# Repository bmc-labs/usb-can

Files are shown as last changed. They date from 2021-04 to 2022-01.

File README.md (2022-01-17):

# `usb-can`, a simple and cost effective CAN link

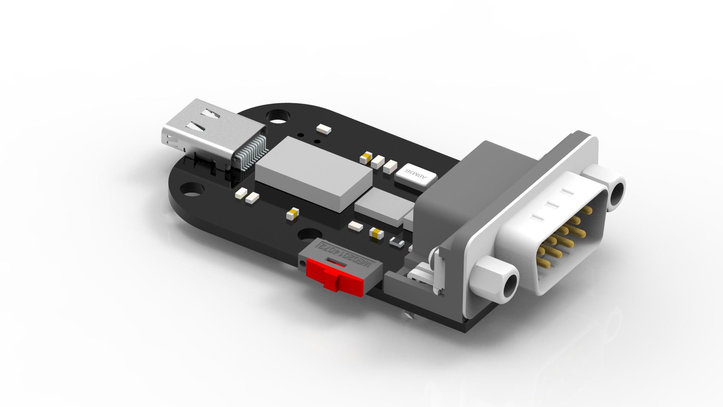
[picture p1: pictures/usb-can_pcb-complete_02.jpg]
bmc::labs

_Rendering of `usb-can`, our version of the USBtin by Thomas Fischl_

Be it for automation, development or debugging, one often needs a way to
inspect a CAN bus. This device allows to connect to a CAN bus via a standard
USB type C cable. It is based on the [USBtin by Thomas
Fischl](https://www.fischl.de/usbtin/) - there are many great resources behind
this link, and we encourage you to buy Thomas' version from him!

All examplatory output comes from a 2013 MacBook Pro running Debian.

## Use with Linux
Start by adding yourself to the `dialout` group if you aren't already in it:

```bash
» sudo usermod -aG dialout $USER
```

You'll need [`can-utils` for Linux](https://github.com/linux-can/can-utils).
If you're on something Debian-based, you're best off installing them like so:

```bash
» sudo apt install can-utils
```

If you're on a different distro, you may find the `can-utils` in your
respective package management; if not go get them [from
GitHub](https://github.com/linux-can/can-utils). Good, now you're all set.

#### Loading kernel modules
CAN support via `socketcan` is upstream in Linux, but it is not necessarily
loaded by default. Execute load like so:

```bash
» sudo modprobe can
» sudo modprobe can-raw
» sudo modprobe slcan
```

You can use the `lsmod` utility to verify everything has worked:

```bash
» lsmod | grep can
slcan                  16384  0
can_raw                20480  0
can                    24576  1 can_raw
```

You output may look slightly different, but you should see the modules loaded.

#### Check which serial device is the CAN device
There are a number of ways to do this. First off, you may want to check that
the `usb-can` is actually recognized via `lsusb` (which you may have to
install):

```bash
» lsusb
...
Bus 002 Device 015: ID 04d8:000a Microchip Technology, Inc. CDC RS-232 Emulation Demo
...
```

If the device shows up here, you can look which serial port it is bound to:

```bash
» sudo tail /var/log/kern.log
Apr 18 14:53:17 rzrgrl kernel: [64635.125815] usb 2-2: new full-speed USB device number 15 using xhci_hcd
Apr 18 14:53:17 rzrgrl kernel: [64635.276572] usb 2-2: New USB device found, idVendor=04d8, idProduct=000a, bcdDevice= 1.00
Apr 18 14:53:17 rzrgrl kernel: [64635.276580] usb 2-2: New USB device strings: Mfr=1, Product=2, SerialNumber=0
Apr 18 14:53:17 rzrgrl kernel: [64635.276583] usb 2-2: Product: USBtin
Apr 18 14:53:17 rzrgrl kernel: [64635.276585] usb 2-2: Manufacturer: Microchip Technology, Inc.
Apr 18 14:53:17 rzrgrl kernel: [64635.277670] cdc_acm 2-2:1.0: ttyACM0: USB ACM device
```

In this case, it is `ttyACM0`, which should be similar for you.

#### Attach the device to a socket-capable interface
The following commands come from `can-utils`, so if you haven't installed those
so far, do that now.

Next, you should select the bus speed of the CAN you're trying to connect to.
The available speeds are:

| Baudrate (kBaud) | Number encoding | Command paramete |
| :---: | :---: | :---: |
| 1.000 | 8 | `-s8` |
| 800 | 7 | `-s7` |
| 500 | 6 | `-s6` |
| 250 | 5 | `-s5` |
| 125 | 4 | `-s4` |
| 100 | 3 | `-s3` |
| 50 | 2 | `-s2` |
| 20 | 1 | `-s1` |
| 10 | 0 | `-s0` |

Setting up a 500 kBaud CAN interface at serial port `ttyACM0` is done like so:

```bash
» sudo slcan_attach -f -s6 -o /dev/ttyACM0
attached tty /dev/ttyACM0 to netdevice slcan0
» sudo slcand ttyACM0 slcan0
» sudo ip link set slcan0 up
```

**Congratulations, you've done it!**

Now you can send and receive CAN messages on the socket interface `slcan0`. For
example, to dump all incoming messages to the terminal:

```bash
» candump slcan0
```

The `candump` utility also allows you to filter for CAN IDs, set up the byte
order, and a number of other useful things it will tell you about if you as it
nicely (`candump -h`).

Sending a frame to CAN is similarly easy:

```bash
» cansend slcan0 7ff#deadbeef
```

The `cansend` utility is also very vocal about its capabilities if asked.

Further useful components of `can-utils`:

1. the `canplayer` utility, which lets you play CAN messages from a log file
    that looks like this:

    ```
    (0.100) slcan0 5D1#0000
    (0.200) slcan0 271#0100
    (0.300) slcan0 289#72027000
    (0.400) slcan0 401#081100000000
    ```

    The first column is a timestamp allowing for time controlled dumping of the
    frames, the second and third are (hopefully) self-explanatory by now.
2. the `canbusload` utility for analyzing the load on the bus.

Both utilities will also happily tell you about themselves with `-h`.

#### Usage example
Last but not least, here is a snippet for sending the current time in the
format `{hour}{minute}` to the CAN on ID `0x7ff`, i.e. the last and therefore
least priority ID, every 5 seconds:

```bash
while true
do
  cansend slcan0 7ff#$(printf '%02x%02x' $(date +"%I") $(date +"%M"))
  sleep 5
done
```

## Use with Windows, macOS

Please find hints for Windows on [Thomas Fischl's
website](https://www.fischl.de/usbtin/).

For macOS, there is code floating around the web for
[`socketcan`](https://github.com/duraki/socketcanx/) and for
[`can-utils`](https://github.com/carloop/can-utils-osx), and once you have
those working the above guide for Linux should mostly apply. No idea if it
works, though - we don't do macOS right now.

---
_The contents of this repository which are our original work are released into
the public domain unter The Unlicense (see [LICENSE](./LICENSE)). We build
heavily on the work of others here and recommend you pay them tribute first if
you like the material you've found here._

## Create your own

### Bill of Materials
- 1x [usb-can_housing-lower](https://gitlab.bmc-labs.com/bmc-board/usb-can/-/blob/trunk/design-files/usb-can_housing-lower.step) (3d print)
- 1x [usb-can_housing-lower-clean](https://gitlab.bmc-labs.com/bmc-board/usb-can/-/blob/trunk/design-files/usb-can_housing-upper-clean.step) or [-icon](https://gitlab.bmc-labs.com/bmc-board/usb-can/-/blob/trunk/design-files/usb-can_housing-upper-icon.step) version (3d print)
- 4x [Socket screw M3x8mm](https://uk.rs-online.com/web/p/socket-screws/1871213)
- 4x [Thread insert M3x4.78mm](https://uk.rs-online.com/web/p/threaded-inserts/0278534/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)
- 1x usb-can PCB board

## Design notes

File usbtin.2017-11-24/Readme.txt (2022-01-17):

USBtin - Simple USB to CAN interface
------------------------------------

This archive contains firmware, drivers and bootloader for the USBtin project.
USBtin is a simple USB to CAN interface. You find further information about
USBtin on the project homepage: http://www.fischl.de/usbtin

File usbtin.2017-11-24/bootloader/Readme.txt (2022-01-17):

Bootloader for USBtin
---------------------

The bootloader for USBtin is adapted from Microchips USB HID Bootloader for
PIC18 Non-J Families (/microchip/mla/v2015_08_10/apps/usb/device/bootloaders/
firmware/pic18_non_j).

Device:
USBtin with PIC18F14K50

Changes:
- Use Jumper to enter bootloader
- Set up clock from MCP2515
- Disabled EEPROM functions to reduce code size
- Added USB serialnumber string

Licence:
The bootloader is closed source. The binary (hex) file is provided free for
personal use. For closed or commercial projects you have to contact the author
to get the permission for using this source code.

Usage:
Program the bootloader into the device/USBtin with a programmer which
supports PIC18 controllers (e.g. PicKit 3).
To enter the bootloader, set the bootloader jumper (JP1) on USBtin before
connecting it to the USB. Then you can use a loader application to update the
firmware. "mphidflash" is such an application. Example:
mphidflash -write USBtin_firmware_v1.x.hex
After flashing a new fimware, disconnect the USBtin from the USB and open the
jumper before reconnecting the device to the host pc.

History:
- 2012-02-09   v1.0    Initial version (based on MLA v2011-10-18-beta)
- 2016-04-13   v1.1    Added USB serialnumber string (based on MLA v2015_08_10)

2016-04-13 Thomas Fischl <tfischl@gmx.de>
http://www.fischl.de/usbtin/

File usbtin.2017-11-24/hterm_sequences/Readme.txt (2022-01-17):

This folder contains HTerm sequence files for the USBtin. HTerm is a terminal program available
for Windows and Linux:
http://www.der-hammer.info/terminal/

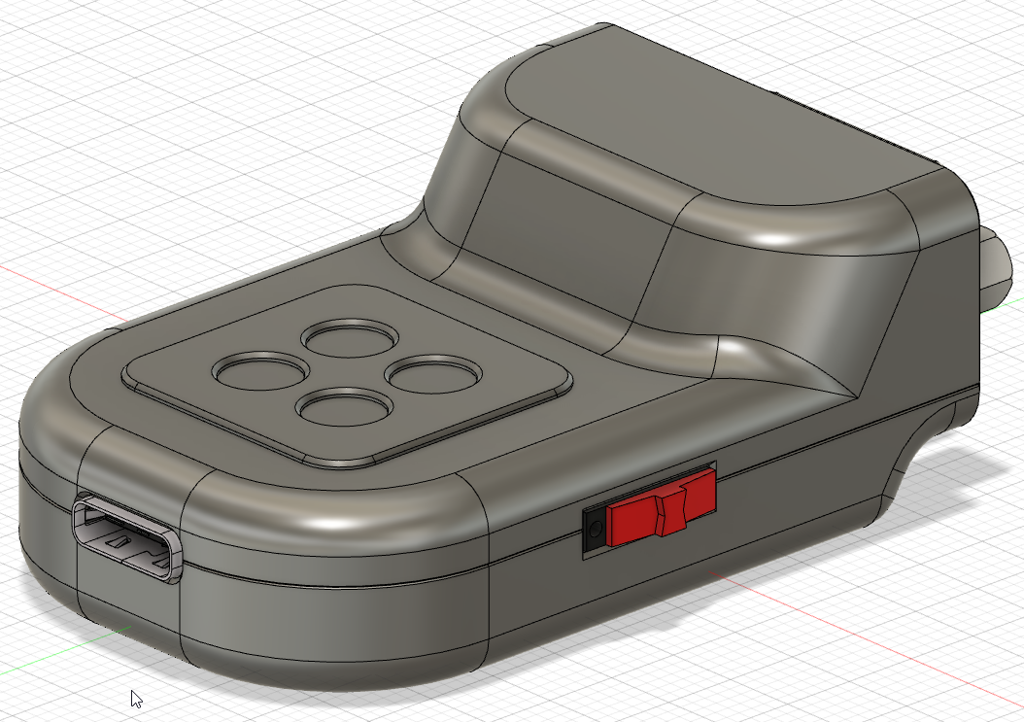
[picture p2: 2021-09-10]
pictures/usb-can_01.png

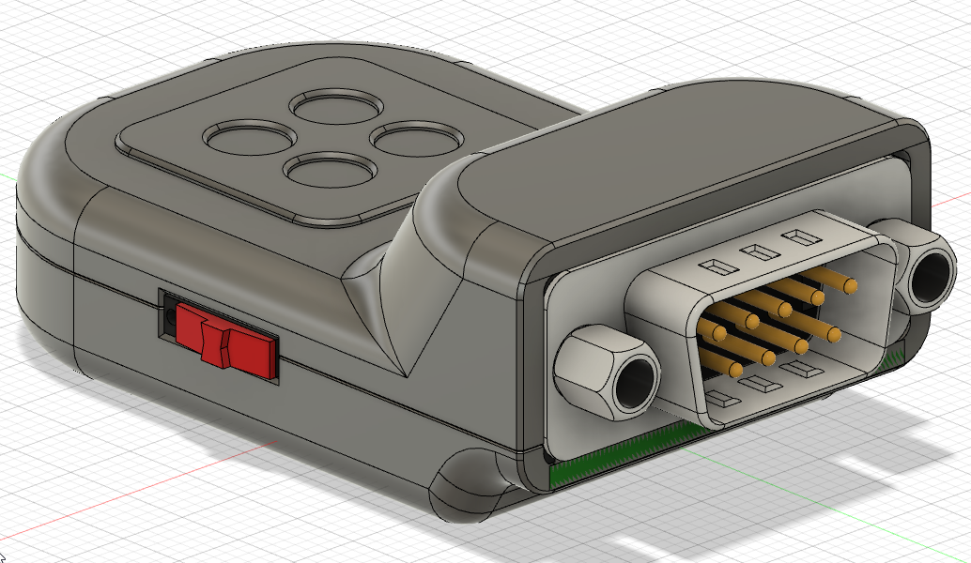
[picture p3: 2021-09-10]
pictures/usb-can_06.png

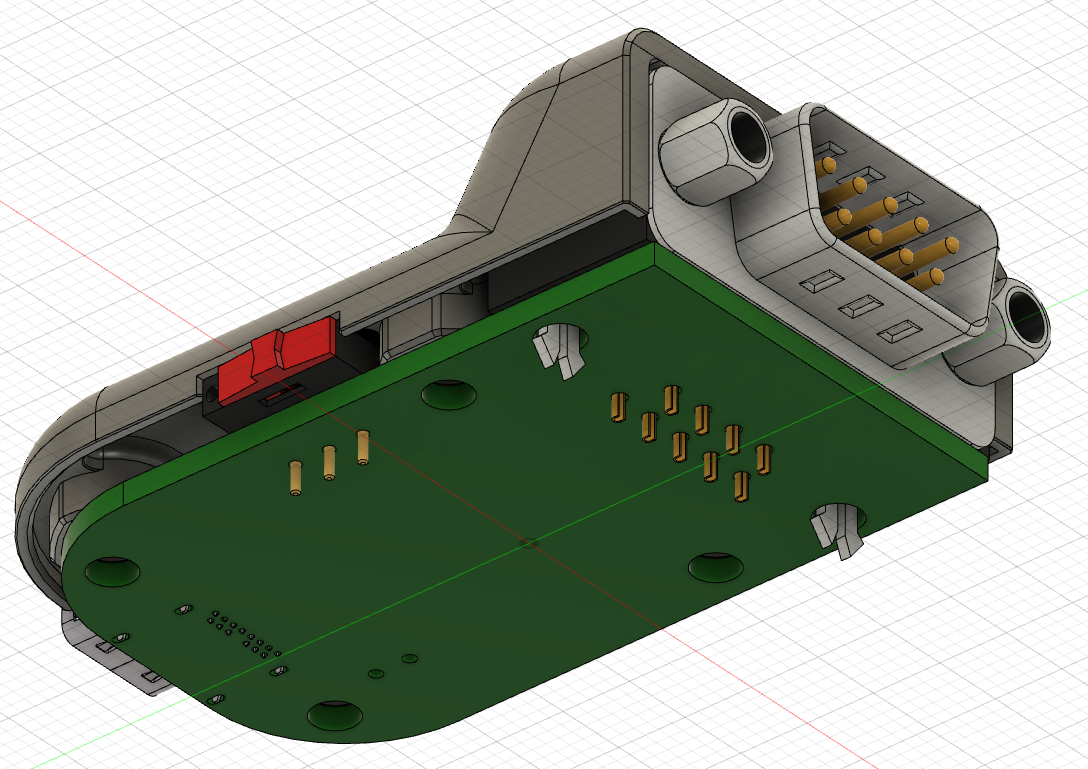
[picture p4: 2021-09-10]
pictures/usb-can_03.png

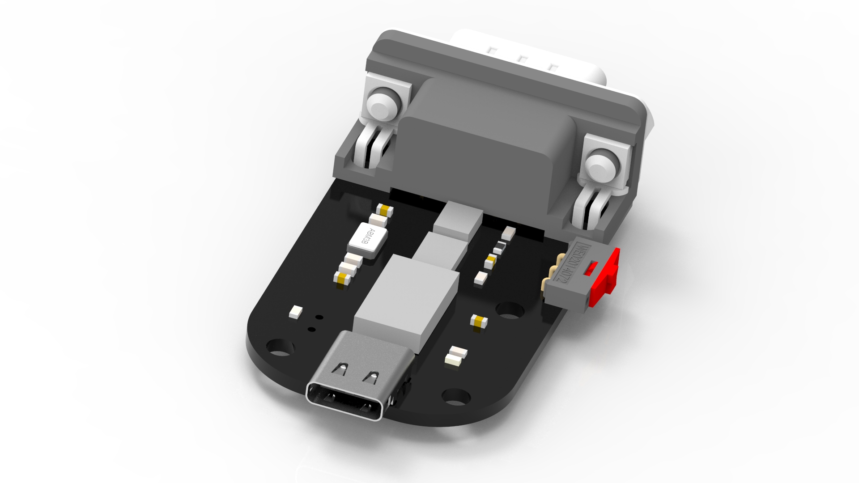
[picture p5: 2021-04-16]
pictures/usb-can_pcb-complete_01.jpg

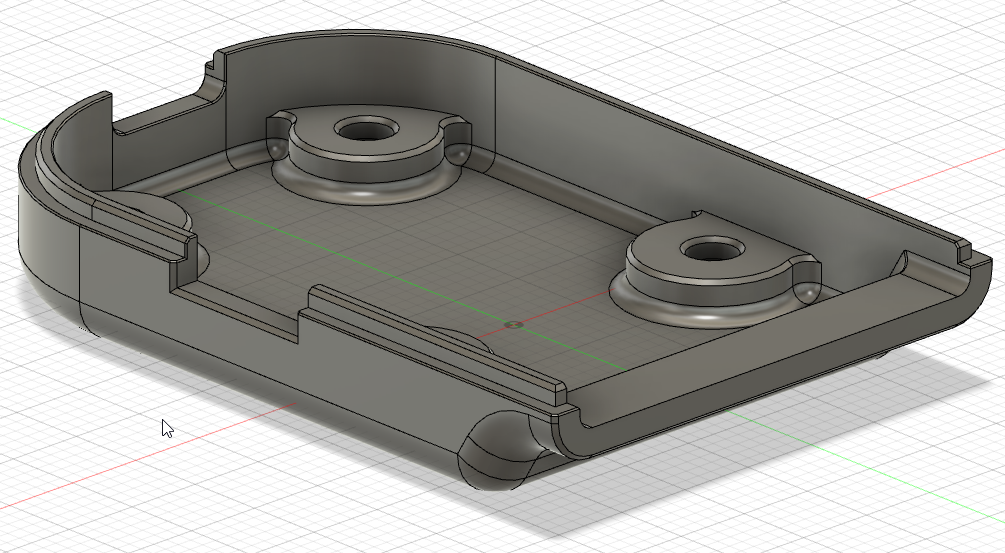
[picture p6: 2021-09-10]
pictures/usb-can_05.png

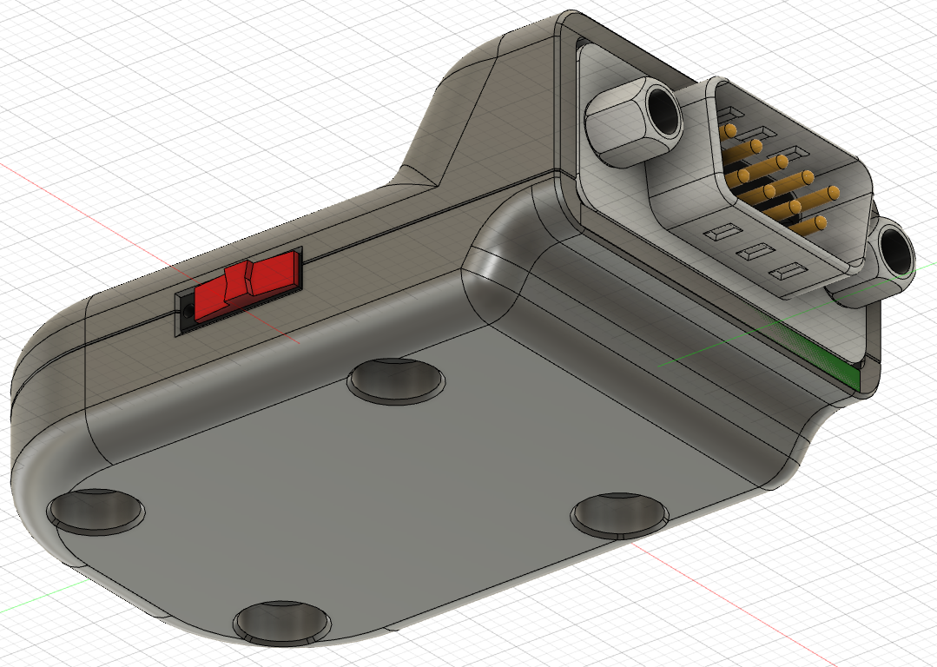
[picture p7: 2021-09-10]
pictures/usb-can_02.png

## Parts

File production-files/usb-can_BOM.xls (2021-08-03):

 |  | Component list |  | usb-can
 |  | Source Data From: |  | USBtin EB.PrjPcb
 |  | Project: |  | USBtin EB.PrjPcb
 |  | Variant: |  | None
 |  | Report Date: | 20.04.2021 | 11:06:44
Description | Manufacturer Part Number | Designator | Quantity | Description | Comment
CAP, 4.7UF, 16V, MLCC, 0603; SVHC: No SVHC (15-Jan-2019) RoHS Compliant: Yes |  | C1 | 1 | CAP, 4.7UF, 16V, MLCC, 0603; SVHC: No SVHC (15-Jan-2019) RoHS Compliant: Yes | 4.7uF
CAP CER 0.1UF 16V 10% X7R 0603 |  | C2, C3, C4, C5 | 4 | CAP CER 0.1UF 16V 10% X7R 0603 | 100nF
CAP CER 22PF 50V 2% NP0 0603 | 06035U220GAT2A | C6, C7 | 2 | CAP CER 22PF 50V 2% NP0 0603 | 22pF
Board-To-Board Connector, Right Angle, WR-PHD Series, Through Hole, Header, 2, 2.54 mm | 61300211021 | J1 | 1 | Board-To-Board Connector, Right Angle, WR-PHD Series, Through Hole, Header, 2, 2.54 mm | Würth Elektronik 61300211021
D Sub Connector, Right Angle, R/a Pcb Mount D Sub, De, Plug, 9, Solder Rohs Compliant: Yes |  | J2 | 1 | D Sub Connector, Right Angle, R/a Pcb Mount D Sub, De, Plug, 9, Solder Rohs Compliant: Yes | Value
Soft Orange 0603 160º 15 mA 1.8 V 7.5 mcd Surface Mount LED | TLMO1000-GS08 | LED1 | 1 | Soft Orange 0603 160º 15 mA 1.8 V 7.5 mcd Surface Mount LED | Vishay TLMO1000-GS08
Res Thin Film 0603 1K Ohm 1% 1/10W ±50ppm/°C Molded SMD SMD Paper T/R | MCT06030C1001FP500 | R1, R3 | 2 | Res Thin Film 0603 1K Ohm 1% 1/10W ±50ppm/°C Molded SMD SMD Paper T/R | 1k
Thick Film Resistors 0603 200ohms 5% Tol | ERJ-3GEYJ201V | R2 | 1 | Thick Film Resistors 0603 200ohms 5% Tol | 200R
Precision resistor, SMD [Panasonic Automotive & Industrial Systems] ERJ3EKF1200V Precision resistor, SMD |  | R4 | 1 | Precision resistor, SMD [Panasonic Automotive & Industrial Systems] ERJ3EKF1200V Precision resistor, SMD | 120R
Metal Film Resistors 10K OHM .1% 25PPM | ERA-3YEB103V | R17 | 1 | Metal Film Resistors 10K OHM .1% 25PPM | 10k
WS-SLTU 10mm*2.5mm, SPDT, ON-ON, 2.54mm, right angle type, THT, Mini Slide Switch, 3 pins | 450302014072 | SW1 | 1 | WS-SLTU 10mm*2.5mm, SPDT, ON-ON, 2.54mm, right angle type, THT, Mini Slide Switch, 3 pins | 450302014072
USB Flash Microcontroller with nanoWatt XLP Technology, 20-pin SOIC, Industrial Temperature, Tape and Reel | PIC18F14K50T-I/SO | U1 | 1 | USB Flash Microcontroller with nanoWatt XLP Technology, 20-pin SOIC, Industrial Temperature, Tape and Reel | PIC18F14K50T-I/SO
Automotive Catalog EMC Optimized CAN Transceiver, 70 mA, 5 V, -40 to 125 degC, 8-pin SOIC (D), Green (RoHS & no Sb/Br) | SN65HVD1050QDRQ1 | U2 | 1 | Automotive Catalog EMC Optimized CAN Transceiver, 70 mA, 5 V, -40 to 125 degC, 8-pin SOIC (D), Green (RoHS & no Sb/Br) | SN65HVD1050QDRQ1
MCP2515 Series 5.5 V 1 Mb/s Stand Alone SPI Interface CAN Controller- TSSOP-20 | MCP2515T-I/ST | U3 | 1 | MCP2515 Series 5.5 V 1 Mb/s Stand Alone SPI Interface CAN Controller- TSSOP-20 | COM-CAN-MCP2515-20
USB 3.1 Type C Receptacle WR-COM, Horizontal, SMT / THT | 632723100011 | USB | 1 | USB 3.1 Type C Receptacle WR-COM, Horizontal, SMT / THT | Würth Elektronik 632723100011
Ceramic SMD Crystal, 24 MHz, +/- 20 ppm, 50 Ohm, -20 to 70 degC, 4-Pin SMD, RoHS, Tape and Reel | ABM3B-24.000MHZ-B2-T | X1 | 1 | Ceramic SMD Crystal, 24 MHz, +/- 20 ppm, 50 Ohm, -20 to 70 degC, 4-Pin SMD, RoHS, Tape and Reel | Abracon ABM3B-24.000MHZ-B2-T

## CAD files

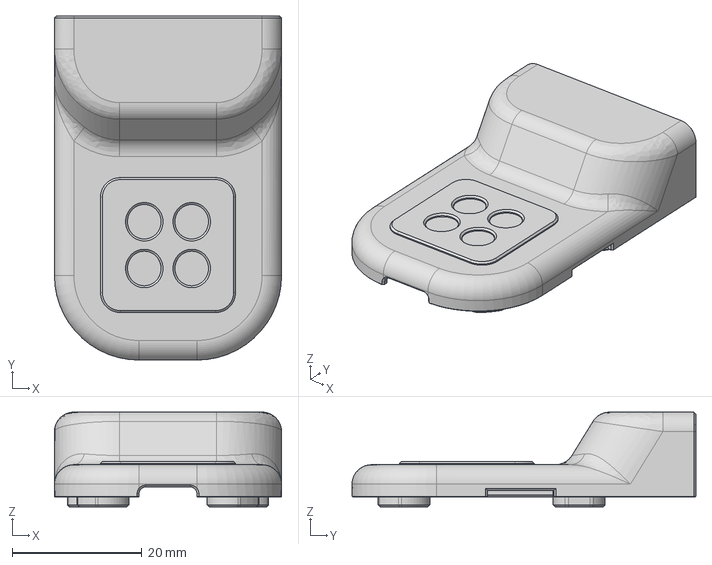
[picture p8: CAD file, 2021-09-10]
design-files/usb-can_housing-upper-icon.step
35.0 x 53.0 x 14.6 mm

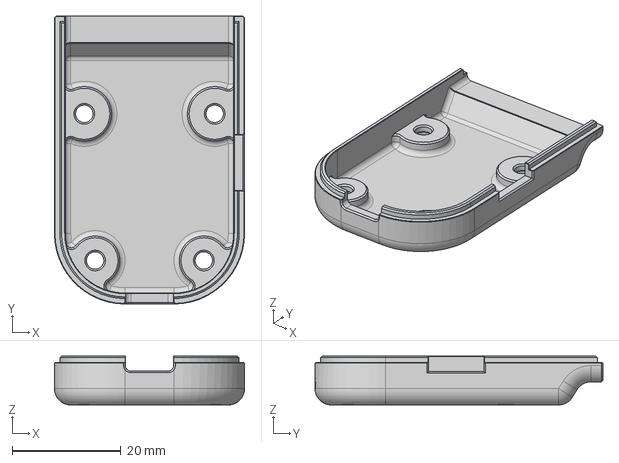
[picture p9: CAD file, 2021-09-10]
design-files/usb-can_housing-lower.step
35.0 x 53.0 x 9.00 mm

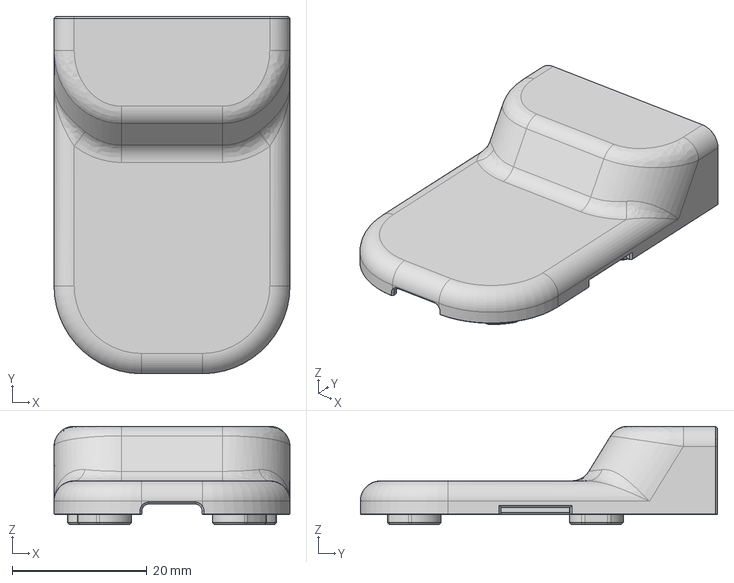
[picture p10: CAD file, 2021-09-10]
design-files/usb-can_housing-upper-clean.step
35.0 x 53.0 x 14.6 mm

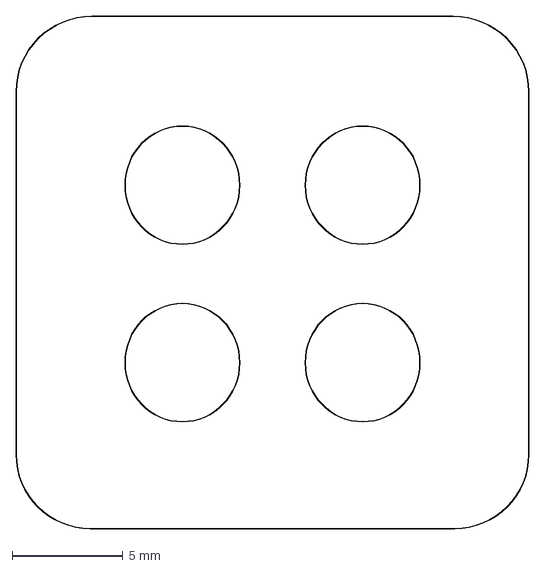
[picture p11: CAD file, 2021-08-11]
design-files/usb-can_sketch-bmc-icon_1.0.0.dxf
23.1 x 23.1 mm

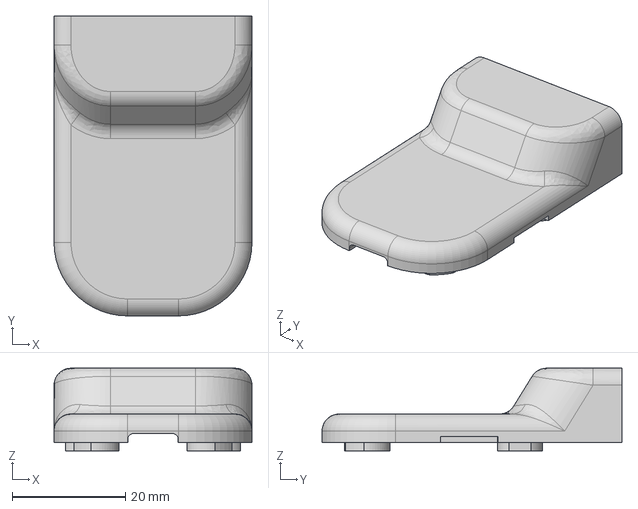
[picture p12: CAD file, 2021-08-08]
design-files/usb-can_v12_housing-upper.step
35.0 x 53.0 x 14.6 mm

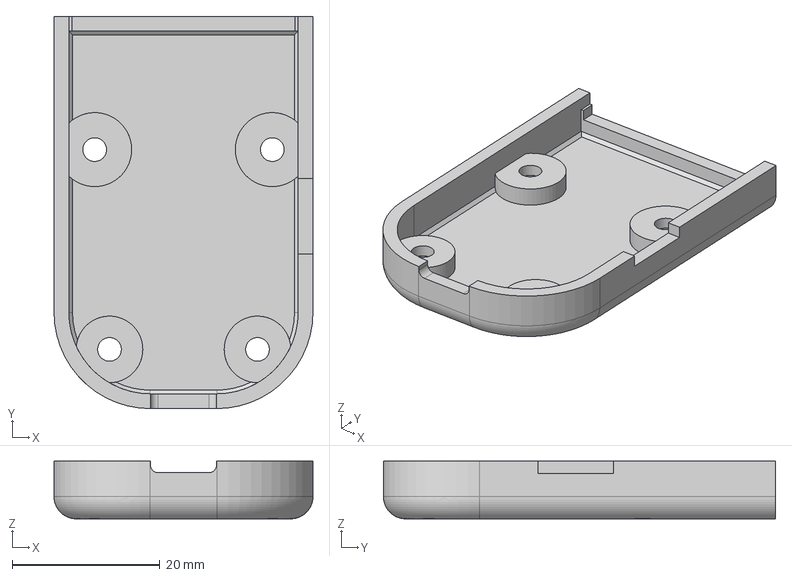
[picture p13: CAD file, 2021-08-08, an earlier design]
design-files/usb-can_v12_housing-lower.step
35.0 x 53.0 x 7.80 mm

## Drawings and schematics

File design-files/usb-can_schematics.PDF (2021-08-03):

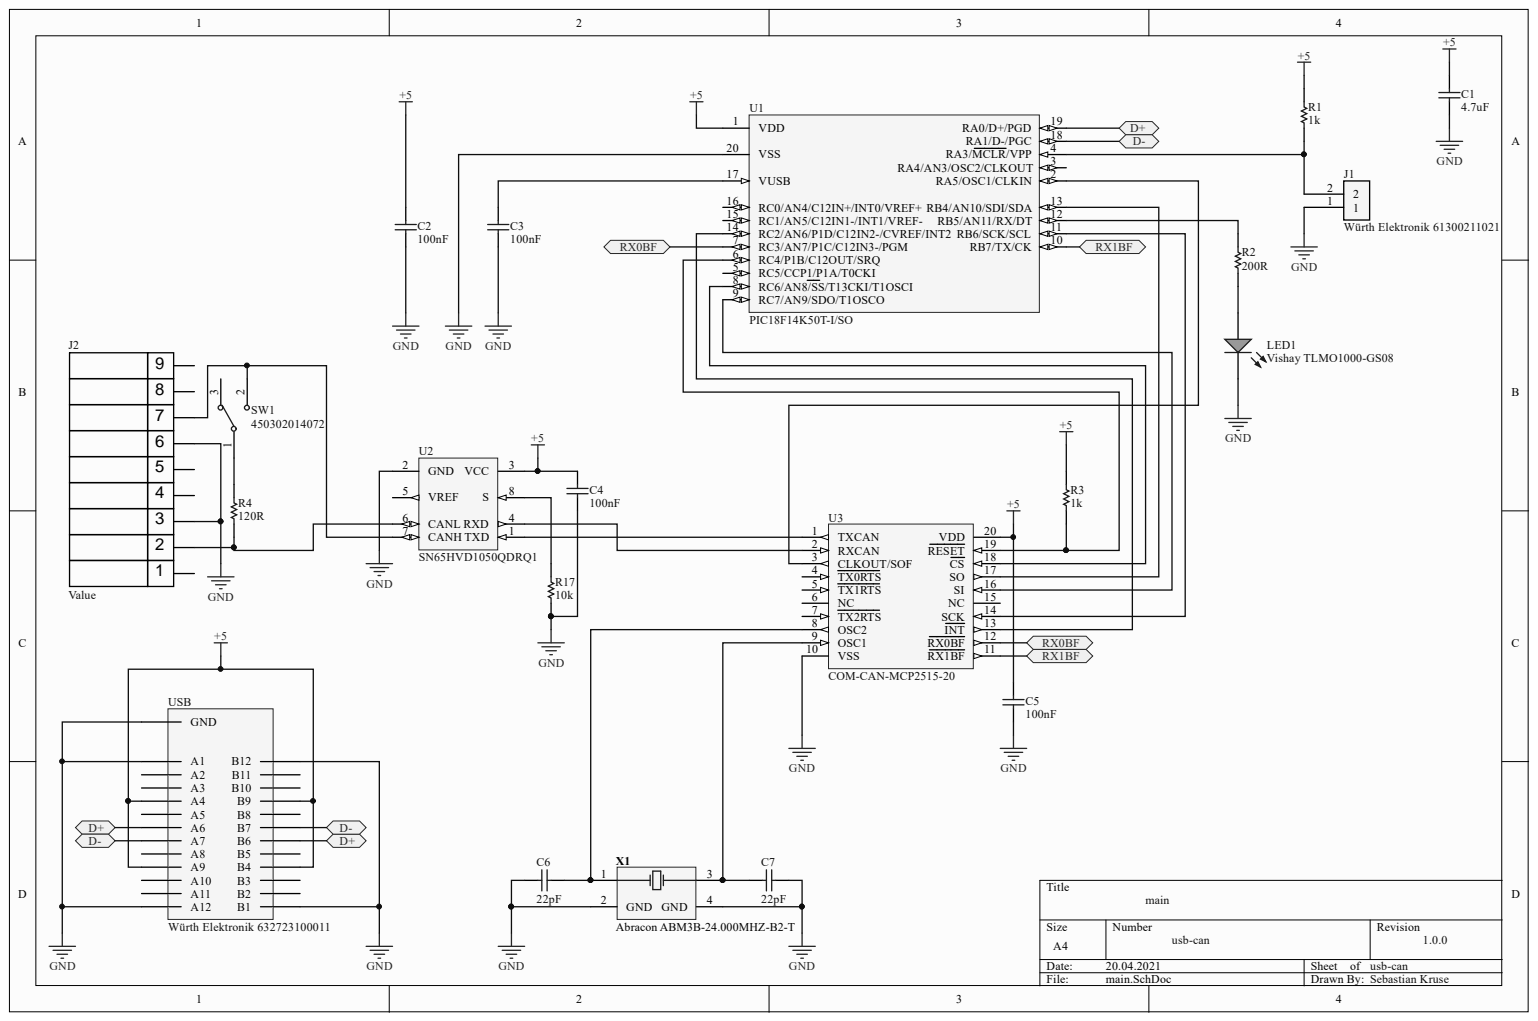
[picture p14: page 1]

2 | 17 CS 18 RESET 19 VDD 20 6 SO

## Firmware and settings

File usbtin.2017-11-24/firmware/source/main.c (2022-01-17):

/********************************************************************
 File: main.c

 Description:
 This file contains the main logic of the USBtin project.
 USBtin is a simple USB to CAN interface. It uses the USB class CDC
 to connect to the host. Configuration and bus communication is
 handled over this CDC virtual comport.

 Authors and Copyright:
 (c) 2012-2017, Thomas Fischl (http://www.fischl.de/contact.html)

 Device: PIC18F14K50
 Compiler: Microchip MPLAB XC8 C Compiler V1.44

 License:
 This file is part of the USBtin firmware project and is copyrighted by the
 authors listed above. It is free for private or educational non-commercial use
 (for a commercial license please contact the authors). It may not be
 redistributed without the prior written consent of the authors.
 
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
 ********************************************************************/

#include <htc.h>
#include <stdio.h>
#include <string.h>
#include "usb_cdc.h"
#include "clock.h"
#include "mcp2515.h"
#include "frontend.h"
#include "usbtin.h"

volatile unsigned char state = STATE_CONFIG;


/**
 * Main function. Entry point for USBtin application.
 * Handles initialization and the the main processing loop.
 */
void main(void) {

    // disable all analog pin functions, set led pin to output
    ANSEL = 0;
    ANSELH = 0;
    TRISBbits.TRISB5 = 0;
    hardware_setLED(0);

    // initialize MCP2515 (reset and clock setup)
    unsigned char selftest = mcp2515_init();
   
    // switch (back) to external clock (if fail-safe-monitor switched to internal)
    OSCCON = 0x30;

    // initialize modules
    clock_init();
    usb_init();
    
    // buffer for incoming characters
    char line[LINE_MAXLEN];
    unsigned char linepos = 0;
    
    canmsg_t canmsg_buffer[CANMSG_BUFFERSIZE];
    unsigned char canmsg_buffer_filled = 0;
    unsigned char canmsg_buffer_canpos = 0;
    unsigned char canmsg_buffer_usbpos = 0;
    unsigned char rxstep = 0;
    
    unsigned short led_lastclock = TMR0;
    unsigned char led_ticker = 0;
    unsigned char reportstatus_timeout = 0;
    unsigned char reportedStatus = 0;


    // main loop
    while (1) {

        // do module processing
        usb_process();
        clock_process();

        // handles rx interrupt requests of MCP2515 controller: receive message and store it to buffer
        while ((state != STATE_CONFIG) && (mcp2515_getPinstateRX0BF() || mcp2515_getPinstateRX1BF()) && (canmsg_buffer_filled < CANMSG_BUFFERSIZE) && (mcp2515_receive_message(&canmsg_buffer[canmsg_buffer_canpos]))) {
                canmsg_buffer_canpos = (canmsg_buffer_canpos + 1) % CANMSG_BUFFERSIZE;
                canmsg_buffer_filled++;                            
        }        

        if (!sendbuffer_isEmpty() && (rxstep == 0)) {

            while (usb_ep1_ready() && !sendbuffer_isEmpty()) {
                sendbuffer_send();
            }
            
        } else {

            // process can messages in receive buffer
            while (usb_ep1_ready() && (canmsg_buffer_filled > 0)) {
                usb_putch(canmsg2ascii_getNextChar(&canmsg_buffer[canmsg_buffer_usbpos], &rxstep));
                if (rxstep == RX_STEP_FINISHED) {
                    // finished this frame
                    rxstep = 0;
                    canmsg_buffer_usbpos = (canmsg_buffer_usbpos + 1) % CANMSG_BUFFERSIZE;
                    canmsg_buffer_filled--;
                    break;
                }
            }

        }
        
        // receive characters from virtual serial port and collect the data until end of line is indicated
        while (usb_chReceived() && (rxstep == 0) && sendbuffer_isEmpty()) {
            unsigned char ch = usb_getch();

            if (ch == CR) {
                line[linepos] = 0;
                parseLine(line);
                linepos = 0;
            } else if (ch != LR) {
                line[linepos] = ch;
                if (linepos < LINE_MAXLEN - 1) linepos++;
            }
        }

        // handle error interrupt
        if ((mcp2515_getPinstateInt() || ((reportedStatus != 0) && (reportstatus_timeout == 0))) && (rxstep == 0) && sendbuffer_isEmpty()) {
           
           unsigned char flags = mcp2515_read_errorflags();
           mcp2515_bit_modify(MCP2515_REG_CANINTF, 0x20, 0);
           
           if (flags != reportedStatus) {
               reportedStatus = flags;
               frontend_sendErrorflags(flags);
           }
           
           reportstatus_timeout = 20; // 2s
        }

        // led signaling        
        if ((unsigned short) (TMR0 - led_lastclock) > CLOCK_TIMERTICKS_100MS) {
            led_lastclock += CLOCK_TIMERTICKS_100MS;
            led_ticker++;            
            if (reportstatus_timeout) reportstatus_timeout--;
        }
        if (!selftest) {
            // selftest failed
            hardware_setLED((led_ticker % 4 == 0) && (led_ticker % 32 != 0));
        } else if (!usb_isConfigured()) {    
            // usb is not enumerated/configured
            hardware_setLED((led_ticker % 4 == 0) && (led_ticker % 16 != 0));
        } else {
            hardware_setLED((led_ticker % 16 == 0) || (state != STATE_CONFIG));
        }

        // jump into bootloader, if jumper is closed
        if (hardware_getBLSwitch()) {
            UCON = 0;
            _delay(1000);
            RESET();
        }
    }
}

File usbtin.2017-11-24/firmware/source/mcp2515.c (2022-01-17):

/********************************************************************
 File: mcp2515.c

 Description:
 This file contains the MCP2515 interface functions.

 Authors and Copyright:
 (c) 2012-2017, Thomas Fischl <tfischl@gmx.de>

 Device: PIC18F14K50
 Compiler: Microchip MPLAB XC8 C Compiler V1.37

 License:
 This file is open source. You can use it or parts of it in own
 open source projects. For closed or commercial projects you have to
 contact the authors listed above to get the permission for using
 this source code.

 ********************************************************************/

#include <htc.h>
#include "usbtin.h"
#include "clock.h"
#include "mcp2515.h"

/** current transmit buffer priority */
unsigned char txprio = 3;

/** current rollover ping-pong buffer */
unsigned char current_rx_buffer = 0;

/**
 * \brief Transmit one byte over SPI bus
 *
 * \param c Character to send
 * \return Received byte
 */
unsigned char spi_transmit(unsigned char c) {
    SSPBUF = c;
    while (!SSPSTATbits.BF) {};
    return SSPBUF;
}


/**
 * \brief Write to given register
 *
 * \param address Register address
 * \param data Value to write to given register
 */
void mcp2515_write_register(unsigned char address, unsigned char data) {

    // pull SS to low level
    MCP2515_SS = 0;
   
    spi_transmit(MCP2515_CMD_WRITE);
    spi_transmit(address);
    spi_transmit(data);
   
    // release SS
    MCP2515_SS = 1;
}


/**
 * \brief Read from given register
 *
 * \param address Register address
 * \return register value
 */
unsigned char mcp2515_read_register(unsigned char address) {

    unsigned char data;
   
    // pull SS to low level
    MCP2515_SS = 0;
   
    spi_transmit(MCP2515_CMD_READ);
    spi_transmit(address);   
    data = spi_transmit(0xff); 
   
    // release SS
    MCP2515_SS = 1;
   
    return data;
}


/**
 * \brief Modify bit of given register
 *
 * \param address Register address
 * \param mask Mask of bits to set
 * \param data Values to set
 *
 * This function works only on a few registers. Please check the datasheet!
 */
void mcp2515_bit_modify(unsigned char address, unsigned char mask, unsigned char data) {

    // pull SS to low level
    MCP2515_SS = 0;
   
    spi_transmit(MCP2515_CMD_BIT_MODIFY);
    spi_transmit(address);
    spi_transmit(mask);
    spi_transmit(data);
   
    // release SS
    MCP2515_SS = 1;
}


/**
 * \brief Initialize spi interface, reset the MCP2515 and activate clock output signal
 */
unsigned char mcp2515_init() {

    unsigned char dummy;
    unsigned char selftest = 1;

    // init SPI
    SSPSTAT = 0x40; // CKE=1
    SSPCON1 = 0x21; // 3MHz SPI clock
    dummy = SSPBUF; // dummy read to clear BF
    dummy = 0;

    TRISBbits.TRISB4 = 1; // set TRIS of SDI
    TRISCbits.TRISC6 = 0; // clear TRIS of SS
    TRISCbits.TRISC7 = 0; // clear TRIS of SDO
    TRISBbits.TRISB6 = 0; // clear TRIS of SCK
    TRISCbits.TRISC3 = 1; // RX0BF
    TRISBbits.TRISB7 = 1; // RX1BF
    LATCbits.LATC6 = 1; // SS

    while (++dummy) {};

    // reset device
    LATCbits.LATC6 = 0; // SS
    spi_transmit(0xC0); // reset device
    LATCbits.LATC6 = 1; // SS

    while (++dummy) {};

    mcp2515_write_register(MCP2515_REG_CANCTRL, 0x85); // set config mode, clock prescaling 1:2 and clock output

    // configure filter
    mcp2515_write_register(MCP2515_REG_RXB0CTRL, 0x04); // use filter for standard and extended frames, enable rollover
    mcp2515_write_register(MCP2515_REG_RXB1CTRL, 0x00); // use filter for standard and extended frames

    // initialize filter mask
    mcp2515_write_register(MCP2515_REG_RXM0SIDH, 0x00);
    mcp2515_write_register(MCP2515_REG_RXM0SIDL, 0x00);
    mcp2515_write_register(MCP2515_REG_RXM0EID8, 0x00);
    mcp2515_write_register(MCP2515_REG_RXM0EID0, 0x00);
    mcp2515_write_register(MCP2515_REG_RXM1SIDH, 0x00);
    mcp2515_write_register(MCP2515_REG_RXM1SIDL, 0x00);
    mcp2515_write_register(MCP2515_REG_RXM1EID8, 0x00);
    mcp2515_write_register(MCP2515_REG_RXM1EID0, 0x00);

    mcp2515_write_register(MCP2515_REG_RXF0SIDL, 0x00);
    mcp2515_write_register(MCP2515_REG_RXF1SIDL, 0x08);
    mcp2515_write_register(MCP2515_REG_RXF2SIDL, 0x00);
    mcp2515_write_register(MCP2515_REG_RXF3SIDL, 0x08);

    // do basic self test
    mcp2515_write_register(MCP2515_REG_CANINTE, 0x00); // Disable all interrupts on INT pin
    mcp2515_write_register(MCP2515_REG_CANINTF, 0x00); // Clear interrupt flags
    mcp2515_write_register(MCP2515_REG_BFPCTRL, 0x0c); // switch RXnBF pins to digital mode    
    while (++dummy) {};    
    if (mcp2515_getPinstateInt() || !mcp2515_getPinstateRX0BF() || !mcp2515_getPinstateRX1BF()) selftest = 0;
    
    // test RXB0
    mcp2515_write_register(MCP2515_REG_BFPCTRL, 0x1c); // set RX0BF    
    while (++dummy) {};    
    if (mcp2515_getPinstateInt() || mcp2515_getPinstateRX0BF() || !mcp2515_getPinstateRX1BF()) selftest = 0;    
    
    // test RXB1
    mcp2515_write_register(MCP2515_REG_BFPCTRL, 0x2c); // set RX1BF
    while (++dummy) {};    
    if (mcp2515_getPinstateInt() || !mcp2515_getPinstateRX0BF() || mcp2515_getPinstateRX1BF()) selftest = 0;    
        
    // test INT
    mcp2515_write_register(MCP2515_REG_BFPCTRL, 0x0c); // clear RXnBF pins
    mcp2515_write_register(MCP2515_REG_CANINTF, 0x20); // Set error interrupt flag
    mcp2515_write_register(MCP2515_REG_CANINTE, 0x20); // Enable error interrupt
    while (++dummy) {};    
    if (!mcp2515_getPinstateInt() || !mcp2515_getPinstateRX0BF() || !mcp2515_getPinstateRX1BF()) selftest = 0;        
    
    // finish initialization
    mcp2515_write_register(MCP2515_REG_BFPCTRL, 0x0f); // RXnBF interrupts to pins
    mcp2515_write_register(MCP2515_REG_CANINTF, 0x00); // Clear interrupt flags
    mcp2515_write_register(MCP2515_REG_CANINTE, 0x00); // Disable all interrupts on INT pin
    
    return selftest;
}
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

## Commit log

2021-04-20 Add design and production files for usb-can
    [Pick Place for usb-can.csv, usb-can-BOM.xls]
2021-07-26 Add .step files of v7, raw, full function
    [usb-can_housing_lower_v7.step, usb-can_housing_upper_v7.step]
2021-07-26 Add .f3d, fusion file
    [design-files_USBtin_EB v7.f3d]
2021-07-26 Add, v8, camfter, fillet
    [usb-can_housing_lower_v8.step, usb-can_housing_upper_v8.step]
2021-07-28 Add .step for usb-can_round_v3 Update rename pictures "redesign_usb-can"->"usb-can_round"
    [usb-can_round_housing_lower_v3.step, usb-can_round_housing_upper_v3.step]
2021-08-03 Change, cleanup, rename and add latest design files from usb-can housing. related to issue #3
    [design-files_USBtin_EB v7.f3d, usb-can_housing-lower_v2.step, usb-can_housing-upper_v2.step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]
2021-08-03 Change, further renaming on repo files, related to Issue #3
    [usb-can_BOM.xls, usb-can_PickPlace.csv]
2021-08-06 Update usb-can to related design issues of #5
    [usb-can_housing_lower_v3.step, usb-can_housing_upper_v3.step, usb-can_v12.f3d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]
2021-08-11 Add bmc-icon on housing
    [usb-can_2.13.0.f3d, usb-can_housing-lower_2.13.0.step, usb-can_housing-upper-clean_2.13.0.step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]
2021-08-16 Add BoM to README.md
2021-08-16 Update housing from Simon Natterer
    [usb-can_housing-lower_2.14.0_SNa.stp, usb-can_housing-upper-clean_2.14.0_SNa.stp, usb-can_housing-upper-icon_2.14.0_SNa.stp]
2021-08-16 Update based on "Simon Natterer" version
    [usb-can_2.13.0.f3d, usb-can_2.18.0.f3d, usb-can_housing-lower_2.13.0.step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]
2021-08-25 Add step in housing-lower, Drop version numbers since GitLab will track updates
    [usb-can_2.18.0.f3d, usb-can_housing-lower.step, usb-can_housing-lower_2.14.0_SNa.stp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]
